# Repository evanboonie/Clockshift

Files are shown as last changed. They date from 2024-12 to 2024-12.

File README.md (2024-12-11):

# Clockshift
Vairable clock generator that fits into a 14-DIP oscillator socket. Also includes a 8-DIP/4-SOJ adapter with optional 4-SOJ disable switch. Primairly intended for overclocking old computers.

## DigiKey Sourcing
Here is a [shared list on DigiKey](https://www.digikey.com/en/mylists/list/JQZCK1QVDC) to help simplify component sourcing.

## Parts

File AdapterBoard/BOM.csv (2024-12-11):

Reference | Value | Datasheet | Footprint | Qty | DNP
J1 | 1107741 | https://www.arieselec.com/wp-content/uploads/2020/02/14005-oscillator-socket.pdf | 14-DIP | 1
J2 | 220-1-08-003 | https://www.cnctech.us/pdfs/220-1-XX-00X_.pdf | 8-DIP | 1
SW1 | CHS-01TB | https://www.nidec-components.com/e/catalog/switch/chs.pdf | Custom Gull Wing | 1

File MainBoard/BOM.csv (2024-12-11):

Reference | Value | Datasheet | Footprint | Qty | DNP
C1 | 1n | https://mm.digikey.com/Volume0/opasdata/d220001/medias/docus/609/CL10B102KB8NNNC_Spec.pdf | 0603 | 1
C2 | 0.1u | https://mm.digikey.com/Volume0/opasdata/d220001/medias/docus/729/CL05B104KA5NNNC_Spec.pdf | 0603 | 1
J1 | 220-1-14-003 | https://www.cnctech.us/pdfs/220-1-XX-00X_.pdf | 14-DIP | 1
R1 | 10K | https://api.pim.na.industrial.panasonic.com/file_stream/main/fileversion/9152 | 0603 | 1
RV1 | SM-3TW203 | https://www.nidec-components.com/e/catalog/trimmer/sm-3&sm-31.pdf | Custom J Lead | 1
SW1 | CS-4-13NTA | https://www.nidec-components.com/e/catalog/switch/cs-4.pdf | Custom J Lead | 1
U1 | LTC6905 | https://www.analog.com/media/en/technical-documentation/data-sheets/6905fd.pdf | SOT-23-5 | 1

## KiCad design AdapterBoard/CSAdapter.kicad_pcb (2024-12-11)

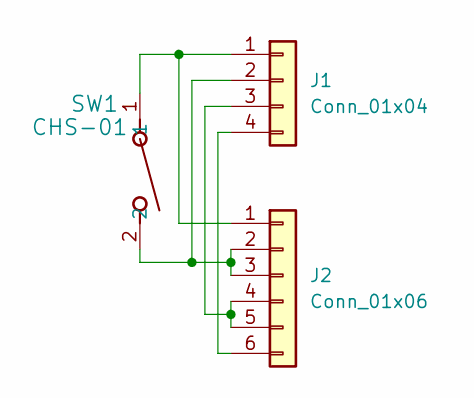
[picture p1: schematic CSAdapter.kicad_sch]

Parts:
J1: Conn_01x04; PinHeader_2x07_4pop_P2.54mmX7.62mm_Vertical
J2: Conn_01x06; PinHeader_2x04_6pop_P2.54mmX7.62mm_Vertical
SW1: CHS-01; CHS-01B_NDC

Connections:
unnamed: J1.1, J2.1, SW1.1
unnamed: J1.2, J2.2, J2.3, SW1.2
unnamed: J1.3, J2.4, J2.5
unnamed: J1.4, J2.6

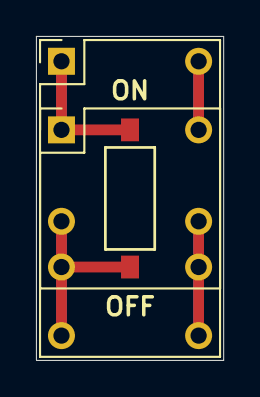
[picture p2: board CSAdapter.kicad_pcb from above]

Board: 2 copper layers, 10.4 x 18.0 mm, 3 parts (0 on the bottom side), 4 nets.

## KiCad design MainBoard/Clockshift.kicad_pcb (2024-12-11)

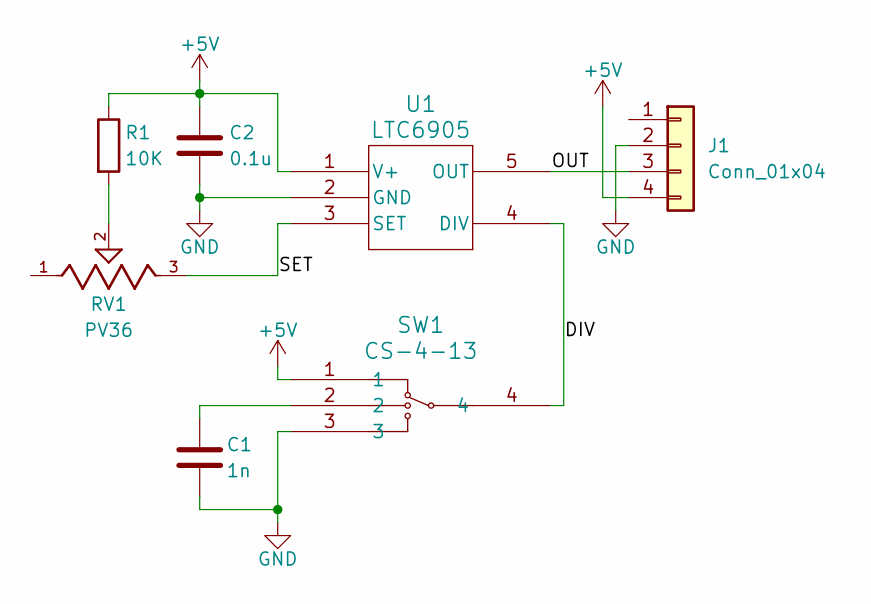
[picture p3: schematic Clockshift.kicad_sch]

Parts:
C1: 1n; C_0603_1608Metric_Pad1.08x0.95mm_HandSolder
C2: 0.1u; C_0603_1608Metric_Pad1.08x0.95mm_HandSolder
J1: Conn_01x04; PinHeader_2x07_4pop_P2.54mmX7.62mm_Vertical
R1: 10K; R_0603_1608Metric_Pad0.98x0.95mm_HandSolder
RV1: PV36; SM-3W
SW1: CS-4-13; CS-4-13NA_NDC
U1: LTC6905; S_5_ADI

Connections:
+5V: C2.1, J1.4, R1.1, SW1.1, U1.1 (V+)
/DIV: SW1.4, U1.4 (DIV)
/OUT: J1.3, U1.5 (OUT)
/SET: RV1.3, U1.3 (SET)
GND: C1.2, C2.2, J1.2, SW1.3, U1.2 (GND)
unnamed: C1.1, SW1.2
unnamed: R1.2, RV1.2

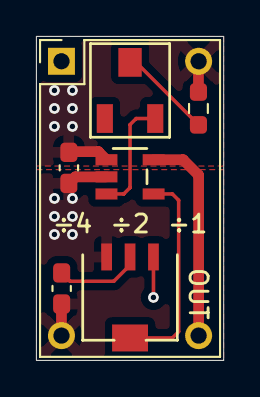
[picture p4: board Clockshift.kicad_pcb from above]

Board: 4 copper layers, 10.4 x 18.0 mm, 7 parts (0 on the bottom side), 7 nets.

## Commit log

2024-12-11 Adding initial libs, schematics, and boards
    [CSAdapter.kicad_pcb, CSAdapter.kicad_sch, Clockshift.kicad_pcb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]
2024-12-11 Adding BOM
2024-12-11 Design rules and gerber files
    [CSAdapter-B_Cu.gbl, CSAdapter-B_Mask.gbs, CSAdapter-B_Paste.gbp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]
2024-12-11 Ignore zipped gerber files
2024-12-11 Fix adapter board for dual layer
    [CSAdapter-B_Cu.gbl, CSAdapter-B_Mask.gbs, CSAdapter-B_Paste.gbp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]
